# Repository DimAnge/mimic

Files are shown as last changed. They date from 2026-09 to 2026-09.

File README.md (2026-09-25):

<p align="center">
  Mimic
</p>

<p align="center">
  A desk buddy that looks back.<br>
  A Raspberry Pi Pico W, a 128&times;64 OLED and two buttons.
</p>

<p align="center">
  
  
  
  
</p>

<p align="center">
  <a href="https://DimAnge.github.io/mimic/"><b>Try the interface in your browser &rarr;</b></a>
</p>

---

Mimic sits next to the keyboard and keeps an eye on things. It knows the weather,
what is playing, how long until the next meeting, how hard the PC is working, and
how much of the Claude usage window is left — and it pulls a face about all of it.

<p align="center">
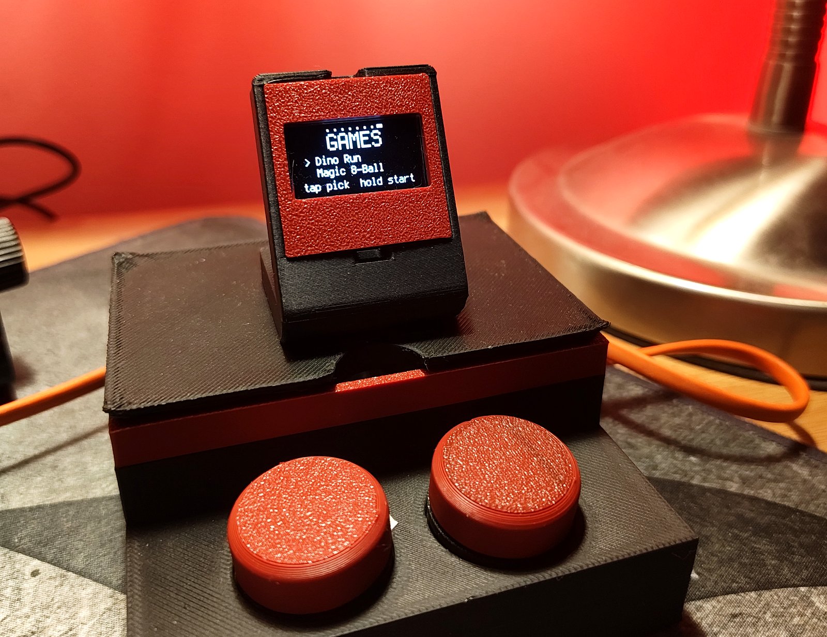
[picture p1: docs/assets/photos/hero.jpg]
Mimic on a desk: a red and black printed case holding an OLED showing the games menu, with two large round buttons in front
  
</p>

<p align="center">
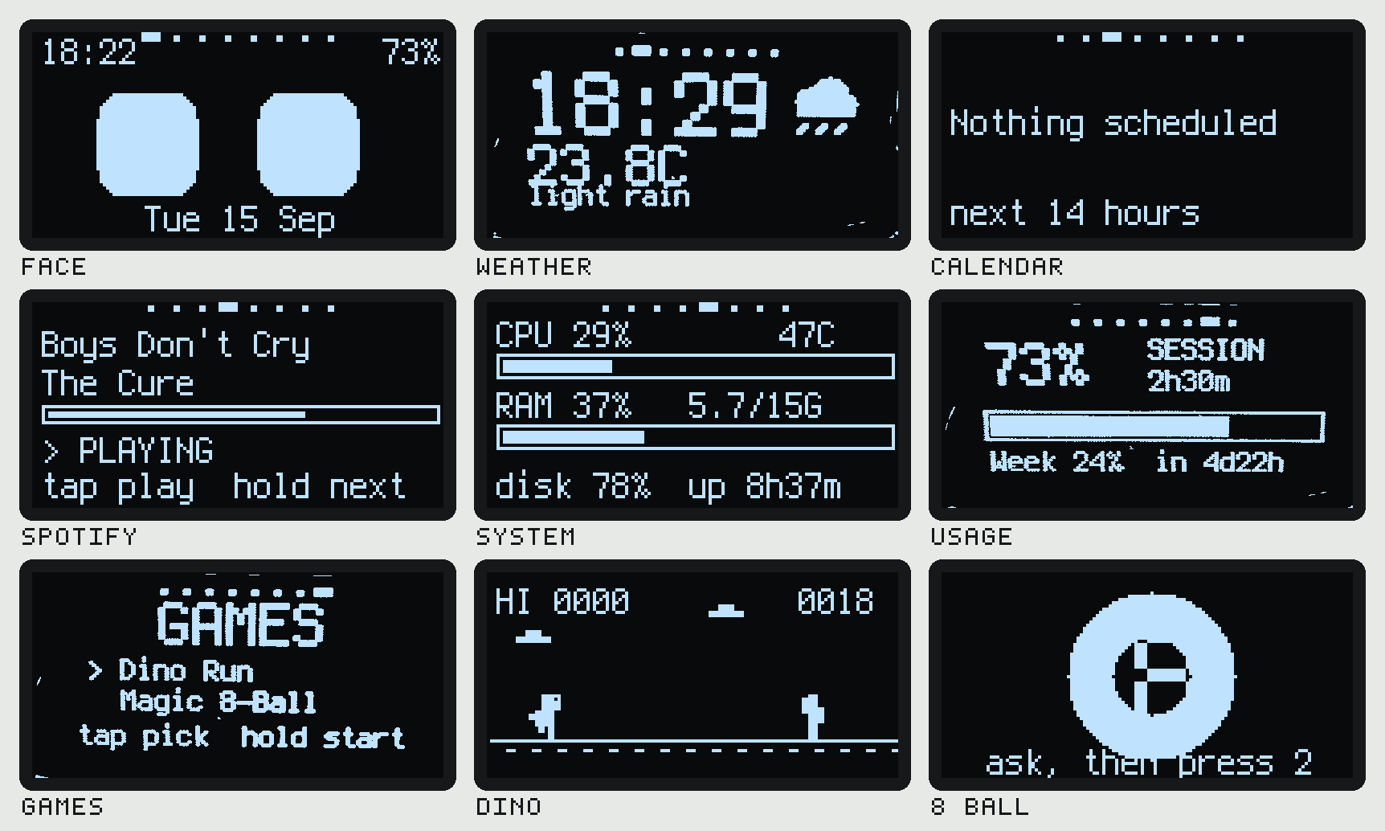
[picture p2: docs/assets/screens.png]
All nine Mimic screens: face, weather, calendar, Spotify, system, usage, games, dino and the magic eight ball
  
</p>

<p align="center">
  <sub>Screens are real frames, not mockups. Most were dumped over USB by
  <code>screenshot.py</code>; the weather, usage and games panels were recovered
  from close-up photographs and thresholded back to two colours.</sub>
</p>

## Why this exists

Mimic started as a private project with two goals: learn electronics properly by
building something that has to work every day, and write Python outside the
analysis scripts I write for work — event loops, hardware constraints, a small
HTTP service, and code that has to survive being unplugged.

It is a learning project, not a product. Some of it is solved the long way round
because the long way round was the point. If you are building your own, the
troubleshooting section below is where most of the learning ended up.

## Contents

- [Why this exists](#why-this-exists)
- [The screens](#the-screens)
- [Controls](#controls)
- [Bill of materials](#bill-of-materials)
- [Wiring](#wiring)
- [Getting it running](#getting-it-running)
- [Configuration](#configuration)
- [How it starts](#how-it-starts)
- [The bridge](#the-bridge)
- [The case](#the-case)
- [Repository layout](#repository-layout)
- [Troubleshooting](#troubleshooting)
- [Roadmap](#roadmap)
- [License](#license)

## The screens

Button 1 walks through the tabs and jumps home when held. Button 2 does whatever
the current tab needs.

| Tab | What it shows | Button 2 |
| --- | --- | --- |
| `FACE` | Animated eyes, a clock, the date, and a note icon while music plays | Cycles the seven moods by hand, for 20 seconds |
| `WEATHER` | A clock big enough to read across the room, temperature and conditions | — |
| `CALENDAR` | The next three events from a private iCal feed | Pages through them |
| `SPOTIFY` | Track, artist and progress, via the Spotify Web API | Tap plays or pauses, hold skips |
| `SYSTEM` | CPU, memory, disk, temperature and uptime of the PC beside it — and the Pico's own IP when the bridge is unreachable | — |
| `TIMER` | Countdown with eight presets from 5 to 60 minutes | Tap starts or stops, hold cycles the preset |
| `USAGE` | Session and weekly Claude usage, with both reset countdowns | — |
| `GAMES` | A menu holding the dino runner and a magic eight ball | Tap moves the cursor, hold starts the game |

Everything the bridge knows arrives in a single `GET /status`, so one request
feeds the calendar, system, usage and Spotify tabs at once.

The two games live in `dino.py` and `eightball.py` and are imported on first
launch rather than at boot — they are the largest modules in the project, and
CircuitPython compiles every `.py` as it imports it, so deferring them cuts
seconds off startup. Inside a game, button 1 backs out to the menu instead of
changing tab.

## Controls

Two buttons, two gestures. A hold is 0.6 s.

| Where | Button 1 | Button 2 tap | Button 2 hold |
| --- | --- | --- | --- |
| Any tab | Next tab | See the table above | See the table above |
| Any tab, held | Home (FACE) | — | — |
| Games menu | Next tab | Move the cursor | Start the selected game |
| In a game | Back to the menu | Jump / shake | — |
| Meeting popup | — | Dismiss | — |

After 45 seconds without a press it returns to FACE on its own — except on
SPOTIFY while something is playing, which stays put.

### What the face is reacting to

Left alone, the mood is not random. Context decides it, in this order, and the
first match wins:

| Priority | Condition | Mood |
| --- | --- | --- |
| 1 | The timer is running | angry — focused, do not disturb |
| 2 | Claude session usage ≥ 90% | surprised |
| 3 | Night | sleepy |
| 4 | The PC has been up more than 2 days | sleepy — it could use a reboot |
| 5 | Music is playing | happy |
| 6 | The weather is notable | sad or happy |
| 7 | Nothing in particular | neutral |

Pressing button 2 on the FACE tab overrides this for 20 seconds, then context
takes over again.

### Screenshots

The SSD1306 cannot be read back — `fill_row` needs a 16-bit colourspace — so
`screenshot.py` walks `display.root_group` and redraws it into a 1-bit buffer,
then prints it over USB. Press `s` in the serial console to capture whatever is
on screen, and `tools/shot.py` turns the dump into a PNG:

```bash
python3 tools/shot.py --paste /tmp/dumps.txt --bezel \
  --names face,calendar,spotify,system,dino,eightball
```

Most screen images in this README came out of that. Three of them would not sit
still long enough to capture — weather, usage and the games menu — so they were
photographed close up instead and put back through `tools/make_photos.py`, which
finds the glass in the photo, squares it to 128 x 64 and thresholds it back to
two colours. Close enough that you cannot tell which is which above.

A meeting popup interrupts any tab when the next calendar event is close.

Burn-in protection runs underneath all of it: the whole frame shifts by a pixel
every few minutes and brightness drops at night. There is no idle sleep — an
idle timeout was tried and removed, because a desk buddy that blanks itself
while you are sitting right there is just a dark rectangle.

## Bill of materials

| Part | Notes |
| --- | --- |
| Raspberry Pi Pico W | Wi-Fi is 2.4 GHz only |
| SSD1306 OLED, 0.96", I2C | 128&times;64, monochrome — there is no colour anywhere in this project |
| 2 &times; tactile buttons | 6&times;6 mm switches on ~25.4 mm pre-assembled discs |
| Passive buzzer module | Plays arbitrary frequencies, so short melodies work |
| Half-size breadboard | Trim the top rail strip so it drops into the tray |
| Female-to-male Dupont jumpers | Nine connections, no soldering |
| USB cable and a 3D printer | For power, code and the case |

## Wiring

<p align="center">
  Mimic wiring map
</p>

| Signal | Pico W pin | Breadboard hole | Goes to |
| --- | --- | --- | --- |
| I2C data | `GP0` — pin 1 | 1a | OLED `SDA` |
| I2C clock | `GP1` — pin 2 | 2a | OLED `SCL` |
| Ground | `GND` — pin 38 | 3j | OLED `GND` |
| 3V3 out | `3V3` — pin 36 | 5j | OLED `VCC` |
| Button 1 | `GP2` — pin 4 | 4a | Button 1 leg A |
| Ground | `GND` — pin 3 | 3a | Button 1 leg B |
| Button 2 | `GP3` — pin 5 | 5a | Button 2 leg A |
| Ground | `GND` — pin 8 | 8a | Button 2 leg B |
| Buzzer signal | `GP15` — pin 20 | 20a | Buzzer `SIG` |
| 5V | `VBUS` — pin 40 | 1j | Buzzer `VCC` |
| Ground | `GND` — pin 18 | 18a | Buzzer `GND` |

The Pico straddles the channel of a half-size breadboard, so row *n* on the `a`
side is physical pin *n*, and row *n* on the `j` side is pin *41 − n*. The buzzer
runs from `VBUS` rather than `3V3`; everything else is on the 3V3 rail.

Breadboard positions for this exact build are in
[`hardware/README.md`](hardware/README.md).

Check every connection against the table before powering anything up, and check
again after any work on the case. Most faults on this build were a connector
that had worked loose, not code.

## Getting it running

**1. Flash CircuitPython.** Hold `BOOTSEL` while plugging the Pico W in, then
drop the `.uf2` onto the `RPI-RP2` drive. It reboots as `CIRCUITPY`.

**2. Add the libraries.** From the matching CircuitPython bundle, copy into
`/lib` on `CIRCUITPY`:

```
adafruit_display_text/
adafruit_displayio_ssd1306.mpy
adafruit_connection_manager.mpy
adafruit_requests.mpy
```

**3. Add your settings.** Copy `settings.toml.example` to `settings.toml` on the
board and fill it in. `settings.toml` is gitignored; keep it that way.

```toml
WIFI_SSID         = "your-network"
WIFI_PASSWORD     = "your-password"
BRIDGE_URL        = "http://192.168.1.42:8080/status"
OPENWEATHER_TOKEN = "your-openweather-key"
```

Find the bridge address with `hostname -I | awk '{print $1}'` on the PC.

**4. Deploy.** All seven files, to the root of the drive, not `/lib`:

```bash
cp code.py app.py eyes.py dino.py eightball.py sfx.py icons.py \
   /media/$USER/CIRCUITPY/ && sync
tio /dev/ttyACM0    # watch it boot
```

`code.py` and `app.py` are a pair and must be deployed together: `code.py` is a
launcher of about fifty lines, and the entire program lives in `app.py`. Copying
one without the other leaves the board running a mismatched half.

Then eject the drive properly before unplugging. `sync` alone is not enough —
see Troubleshooting.

**5. Start the bridge** on the PC Mimic lives next to — see below.

## Configuration

Everything the board needs is in `settings.toml` on the CIRCUITPY drive. There
is no config file in the repository.

| Key | What it does |
| --- | --- |
| `WIFI_SSID` | 2.4 GHz network name — the Pico W radio does not do 5 GHz |
| `WIFI_PASSWORD` | Network password |
| `BRIDGE_URL` | Full URL of the bridge's status endpoint, e.g. `http://192.168.1.42:8080/status`. The Spotify control routes are derived from it |
| `OPENWEATHER_TOKEN` | OpenWeather API key for the weather tab |

The city is set in `app.py` (`CITY = "Athens,GR"`), along with the thresholds
worth knowing about: `MEETING_WARN_MIN` for how far ahead the popup appears,
`UPTIME_TIRED_MIN` and `USAGE_ALERT_PCT` for the mood triggers, and the various
`*_REFRESH` intervals.

## How it starts

`code.py` is a launcher of about fifty lines. It imports `app.py`, which never
returns unless something goes wrong, and handles the two ways it can go wrong on
a desk with no computer attached.

**The network stack can wedge.** On a cold power-on the Pico can join Wi-Fi and
get an address, yet pass no traffic at all: every connection times out with
`EINPROGRESS` and even DNS fails. Once in that state it never recovers on its
own, and rebuilding the socket pool does not help. A soft reset clears it — but
only once the network is genuinely ready, which can take a minute or two after
power-on.

So `app.py` watches for it. Two bridge failures in a row could just mean the PC
is off, so it then tries a DNS lookup: if that fails too while Wi-Fi claims to
be up, the stack is dead rather than the bridge. It raises `NetworkStuck`, and
`code.py` answers with `supervisor.reload()`.

That can only happen ten times. The count lives in `microcontroller.nvm[0]`,
because ordinary variables do not survive a reset. It goes back to zero on a
genuine power-on and on the first successful bridge fetch, so a network that is
merely slow gets as many tries as it needs across boots, while one that is truly
broken cannot reset the board forever. A fresh board's NVM reads 255, which is
treated as zero.

**A crash should not be fatal.** When a CircuitPython program raises, the board
prints the traceback and waits for a keypress on the serial console — which on a
desk looks identical to a dead device. Any other exception is caught, printed,
and followed by a five-second pause and a restart. `Ctrl-C` still drops you into
the REPL, because `KeyboardInterrupt` is not an `Exception` subclass and passes
straight through.

`app.py` also pauses a second on cold boot before touching the OLED: on a
power-on everything wakes at the same instant and CircuitPython gets there
before the display is ready to answer on I2C.

## The bridge

The Pico has no business holding Spotify tokens or a private calendar URL, so it
doesn't. `bridge/bridge.py` is an HTTP server that runs on the PC, listens on
port 8080, and hands back plain integers and pre-formatted strings — the Pico
never parses an ISO timestamp, because CircuitPython has no `datetime`.

| Endpoint | Returns |
| --- | --- |
| `GET /status` | Everything: Claude usage, CPU, memory, disk, temperature, uptime, the next three calendar events, Spotify state, and the wall clock |
| `GET /spotify/playpause` | Toggles playback |
| `GET /spotify/next` | Skips forward |
| `GET /spotify/previous` | Skips back |

The control routes are GETs so the Pico can fire them in one line. Playback
control needs Spotify Premium; reading what is playing works on any account.

`/status` also carries `clock`, which is how the board sets its RTC. A TLS
handshake on a microcontroller costs seconds at boot, and the bridge is already
being talked to over plain HTTP, so it hands over the wall clock and the Pico
skips the HTTPS time sync entirely. HTTPS remains the fallback when the bridge
is unreachable.

Results are cached per source — 60 s for `ccusage`, 4 s for `/proc`, 5 min for
the calendar, 3 s for Spotify — so polling costs almost nothing.

### Setting it up

The calendar needs two packages; everything else is standard library:

```bash
python3 -m venv ~/desky-venv
~/desky-venv/bin/pip install -r bridge/requirements.txt
```

Credentials live in your home directory, never in the repository:

```bash
echo 'https://your-private-ical-url' > ~/.desky-ical-url
echo 'your-spotify-client-id'        > ~/.desky-spotify-client
chmod 600 ~/.desky-ical-url ~/.desky-spotify-client
```

The iCal URL is a bearer credential — anyone holding it can read your calendar.
Then authorise Spotify once, which writes a refresh token to
`~/.desky-spotify.json`:

```bash
~/desky-venv/bin/python bridge/spotify.py
```

It uses the Authorization Code flow with PKCE, so there is no client secret to
store. The redirect URI must be registered in the Spotify dashboard exactly as
`http://127.0.0.1:8888/callback` — Spotify rejects plain HTTP except loopback
literals, and `localhost` does not count as one.

Install the service so it comes back after a reboot:

```bash
mkdir -p ~/.config/systemd/user
cp bridge/mimic-bridge.service ~/.config/systemd/user/
systemctl --user enable --now mimic-bridge
systemctl --user status mimic-bridge --no-pager
```

The unit sets `PYTHONUNBUFFERED=1` so `journalctl --user -u mimic-bridge -f`
shows output as it happens rather than in blocks.

Editing any bridge file leaves the old process running. Restart after every
change:

```bash
systemctl --user restart mimic-bridge
```

`bridge/cal_debug.py` exists only for troubleshooting the calendar feed — it
prints which calendar the URL belongs to and every occurrence it can see.

If the PC sleeps, Mimic falls back to its offline screens rather than hanging.

## The case

Five printed parts: three of mine, two from MakerWorld.

| Part | Source | What it does |
| --- | --- | --- |
| `tray.stl` | Custom, `hardware/case.scad` | Body: breadboard pocket, USB opening on the right wall, button shelf |
| `lid.stl` | Custom, `hardware/case.scad` | Lifts off on a locating lip, with a cable pass-through |
| `spacer.stl` | Custom, `hardware/case.scad` | Sets the stack height inside the tray so the openings line up |
| Screen stand | [Minimalist OLED 0.96" modular case](https://makerworld.com/en/models/2085334-minimalist-oled-0-96-modern-modular-cases#profileId-2253779) by Maker Engineer | Holds the OLED at a readable angle |
| Button assemblies | [Push button assembly](https://makerworld.com/en/models/1791039-push-button-assembly?from=search#profileId-1908757) by Leroyd | The two ~25.4 mm button discs |

Check each MakerWorld licence before reusing those two — most are Creative
Commons and ask for attribution, some forbid commercial use.

### Printing it

1. **Print the two downloaded parts first** with the settings on their model
   pages. They are quick, and they tell you whether your printer holds tolerance
   before you commit hours to the tray.
2. **Print the tray.** 0.2 mm layers, 15% infill, PLA, no supports, open side up.
   Check the breadboard pocket against your actual breadboard while a reprint is
   still cheap.
3. **Print the spacer and the lid.** Same settings.
4. **Clean the openings.** Clear elephant's foot from the counterbores and the
   USB slot with a craft knife until parts seat without force.
5. **Dry fit everything** before wiring: breadboard into the tray, spacer under
   the stack, buttons into the shelf, screen into its stand, cable through the
   slot.
6. **Assemble and re-test.** Seat the Dupont connectors dry and power it up
   before the lid goes on.

Exporting the custom parts:

```bash
openscad -D 'part="tray"'   -o hardware/stl/tray.stl   hardware/case.scad
openscad -D 'part="lid"'    -o hardware/stl/lid.stl    hardware/case.scad
openscad -D 'part="spacer"' -o hardware/stl/spacer.stl hardware/case.scad
```

**Do not glue the Dupont connectors.** Superglue wicks between the metal
contacts and insulates them: the joint looks perfect and conducts nothing. Two
attempts at custom button caps also failed here, both because the boss length
was measured from the wrong reference face — which is why the discs above are a
download rather than a design.

## Repository layout

```
mimic/
├── code.py                 # launcher: stuck-network and crash recovery
├── app.py                  # the program: all eight tabs and the main loop
├── eyes.py                 # the face: moods, blinking, gaze, boot animation
├── dino.py                 # the runner, imported on first launch
├── eightball.py            # the magic eight ball, imported on first launch
├── sfx.py                  # the buzzer and its melody table
├── icons.py                # weather sprites
├── screenshot.py           # framebuffer dumper, see tools/shot.py
├── settings.toml.example   # Wi-Fi, bridge URL and weather key template
├── bridge/
│   ├── bridge.py           # PC-side HTTP service
│   ├── spotify.py          # one-time PKCE login, and the bridge's module
│   ├── cal_debug.py        # calendar feed troubleshooting
│   ├── requirements.txt
│   └── mimic-bridge.service
├── hardware/
│   ├── case.scad           # tray, lid and spacer
│   ├── stl/
│   └── README.md
├── docs/                   # the GitHub Pages site
│   ├── index.html          # one file, includes the browser simulator
│   └── assets/             # logo, favicons, wiring map, social preview
└── tools/                  # shot.py and the asset generators
```

## Troubleshooting

**The board boots to an error after a deploy.** The write did not flush. Copy
again with `&& sync`, eject the drive, and watch the console with
`tio /dev/ttyACM0`.

**A bare `OSError: [Errno 5]` with no traceback.** The filesystem on the board is
corrupted, almost always from unplugging while a write was still in flight.
`sync` flushes your PC's cache, but the Pico can still be mid-write: eject the
drive from the file manager, or `udisksctl unmount -b /dev/sdX1`, before pulling
the cable. To recover, first copy `settings.toml` and `lib/` off the board if
you still can, then in the REPL:

```python
import storage
storage.erase_filesystem()
```

The board reboots with an empty CIRCUITPY drive. Put `lib/`, `settings.toml`
and the seven program files back.

**It will not join the network.** The Pico W radio is 2.4 GHz only. A combined
2.4/5 GHz SSID sometimes works and sometimes does not; give the 2.4 GHz band its
own name if you can.

**No serial device on Linux.** Add yourself to `dialout` and log back in, then
stop ModemManager grabbing the port:

```bash
sudo usermod -aG dialout $USER
sudo systemctl mask ModemManager
```

**A button stopped responding after assembly.** Check for glue before checking
the code. Superglue wicks between Dupont contacts and insulates them perfectly.
Wiggle the connector to crack the joint, re-seat it dry, and let the pinched
barrel do the gripping.

**Python tooling refuses to install.** Check whether conda is shadowing the
system Python with an older version, and point `pipx` at the real one, for
example `/usr/bin/python3.12`.

**`EINPROGRESS` on every request.** Nine times out of ten this is the wrong IP
in `BRIDGE_URL`: the Pico is connecting to an address where nothing answers.
Compare it with `hostname -I` on the PC. PCs on DHCP change address after a
router restart, so give the PC a **DHCP reservation** in the router and the
address stops moving. The remaining case is the cold-boot wedge above, which
`code.py` handles on its own — the screen shows `Network reset n/10` while it
does.

**Everything reads zero, or one section never populates.** Same first check:
`BRIDGE_URL` against `hostname -I`. A wrong address fails quietly. When the
bridge is unreachable the SYSTEM tab shows the Pico's own IP and the last error,
which is usually enough to tell which side is wrong.

**The screen shows stale numbers.** The bridge is not running, or the PC is
asleep. `systemctl --user status mimic-bridge --no-pager`, and
`journalctl --user -u mimic-bridge -f` to watch it live.

**Usage shows `--%`.** The usage tab reads `ccusage json`, and that output format
is undocumented and not a stable API — a Claude Code update can change or
remove it without warning. Run `ccusage json` by hand; if it errors or the keys
have moved, `read_usage()` in `bridge.py` is the place to adapt. If `ccusage` is
not on the service's `PATH`, set `CCUSAGE_BIN` to its full path in the unit.

**The calendar says nothing is scheduled when something is.** The bridge looks
seven days ahead and the tab shows the next three, so an empty tab means the
feed really has nothing timed in that window. Run
`python3 bridge/cal_debug.py`, which prints which calendar the feed belongs to
and every occurrence it can see. All-day entries are ignored on purpose —
birthdays and public holidays are not meetings and should not raise a popup.

## Roadmap

- [x] Face reacts to context — timer, usage, night, uptime, music, weather
- [ ] Persist the dino high score across restarts
- [ ] Top-mounted screen holder integrated into the tray, replacing the separate stand
- [ ] A task button that cycles today's tasks and marks them done

Dropped on purpose: Gmail notifications (too much moving parts for the payoff)
and anything that depends on colour.

## License

MIT — see [LICENSE](LICENSE).

Built with [CircuitPython](https://circuitpython.org/), Adafruit's display
libraries, and [OpenSCAD](https://openscad.org/). The screen stand and button
discs are other people's models — see [The case](#the-case) for links and
licences.

The logo, the wiring diagram, the social image and the project site were made
with help from Claude (Anthropic). The hardware and the mistakes are
mine.

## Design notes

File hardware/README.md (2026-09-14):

# Hardware

## Breadboard layout

The reference build sits on a half-size breadboard with the top rail strip
trimmed off so it drops into the case tray.

| Component | Connection | Breadboard hole |
| --- | --- | --- |
| OLED | `SDA` -> `GP0`, pin 1 | 1a |
| OLED | `SCL` -> `GP1`, pin 2 | 2a |
| OLED | `GND`, pin 38 | 3j |
| OLED | `VCC` -> `3V3`, pin 36 | 5j |
| Button 1 | leg A -> `GP2`, pin 4 | 4a |
| Button 1 | leg B -> `GND`, pin 3 | 3a |
| Button 2 | leg A -> `GP3`, pin 5 | 5a |
| Button 2 | leg B -> `GND`, pin 8 | 8a |
| Buzzer | `SIG` -> `GP15`, pin 20 | 20a |
| Buzzer | `VCC` -> `VBUS`, 5V, pin 40 | 1j |
| Buzzer | `GND`, pin 18 | 18a |

Row *n* on the `a` side of the channel is physical pin *n*; row *n* on the `j`
side is pin *41 − n*. That is the whole trick to reading this table against the
board.

Wire colours used in the diagrams: red for 3V3, dark grey for ground, blue for
I2C data, yellow for I2C clock, green for button inputs, purple for the buzzer
signal.

## Checking the wiring

Check every connection against the table above:

- after wiring, before loading `code.py`
- after any work on the case
- after anything involving glue

## Printed parts

| Part | Source |
| --- | --- |
| `tray.stl` | Custom, `case.scad` |
| `lid.stl` | Custom, `case.scad` |
| `spacer.stl` | Custom, `case.scad` |
| Screen stand | [Minimalist OLED 0.96" modular case](https://makerworld.com/en/models/2085334-minimalist-oled-0-96-modern-modular-cases#profileId-2253779) by Maker Engineer |
| Button assemblies | [Push button assembly](https://makerworld.com/en/models/1791039-push-button-assembly?from=search#profileId-1908757) by Leroyd |

Check the licence on each MakerWorld model before reusing it, and say so here if
you remixed rather than printed as-is.

`case.scad` builds the three custom parts. Set the `part` variable and export:

```bash
openscad -D 'part="tray"'   -o stl/tray.stl   case.scad
openscad -D 'part="lid"'    -o stl/lid.stl    case.scad
openscad -D 'part="spacer"' -o stl/spacer.stl case.scad
```

Print settings: 0.2 mm layers, 15% infill, PLA, no supports. The tray prints
open-side up. Print the two MakerWorld parts first — they are quick, and they
tell you whether your printer is holding tolerance before you commit hours to
the tray.

### Known dimensions (v6)

| Feature | Value |
| --- | --- |
| Breadboard pocket | 85 x 57 mm |
| Button counterbore | 25.39 mm |
| Button disc slot | 22 x 16 mm (clears Dupont connectors) |
| USB opening | right wall |
| Lid | locating lip plus cable pass-through slot |
| Spacer | sets the stack height inside the tray |

### Assembly warning

Do not glue Dupont connectors. Superglue wicks between the metal contacts and
insulates them; the joint looks perfect and conducts nothing. The pinched barrel
grip is enough on its own. If a button has gone dead after assembly, wiggle the
connector to crack any glue and re-seat it dry.

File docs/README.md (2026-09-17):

# The Mimic site

`index.html` is the whole site: one file, no build step, no dependencies beyond
two web fonts. Open it in a browser to work on it.

## Publishing

Either way works. Pick one.

**Branch setting (simplest).** Settings → Pages → Source: *Deploy from a branch*
→ branch `main`, folder `/docs`. Push, wait a minute, done.

**Actions workflow.** Settings → Pages → Source: *GitHub Actions*. The workflow
in `.github/workflows/pages.yml` then publishes `docs/` on every push to `main`.

`.nojekyll` is there so GitHub serves the folder as-is.

## Before the first push

Replace `DimAnge` in these places:

- `docs/index.html` — the `og:url` and `og:image` tags, three GitHub links
- `README.md` — the site link and the footer link

Then set the social image: Settings → General → Social preview → upload
`docs/assets/social-preview.png`.

## Assets

| File | Use |
| --- | --- |
| `logo.svg` | Horizontal lockup, site header and README |
| `logo-mark.svg`, `logo-mark-512.png` | Square mark, avatars |
| `favicon.svg`, `favicon-32.png`, `favicon-180.png` | Browser and iOS icons |
| `wordmark.svg` | Type only |
| `social-preview.png` | 1280×640 card for GitHub, link previews |
| `wiring.svg`, `wiring.png` | The wiring map |
| `screens.png` | Contact sheet, built by `tools/make_sheet.py` from real captures |
| `shots/` | Real screen captures from the device |
| `photos/` | Device photographs, resized by `tools/make_photos.py` |
| `classic/` | The first identity: rounded case, glowing pixel eyes, blue-white screen |
| `alt/` | The two directions not chosen — stamp and sketch, see `alt/compare.png` |

The current identity is the bracket mark: a face held in square brackets, one
ink, no bezel and no glow. It is generated by `tools/make_bracket_assets.py`.

Everything is generated geometry — no fonts are needed to render the logos, so
they survive being embedded anywhere.

To go back to the first identity, copy `classic/` over the top:

```bash
cp docs/assets/classic/* docs/assets/
```

Regenerate after editing the scripts in `tools/`:

```bash
pip install cairosvg
python3 tools/make_assets.py
python3 tools/make_wiring.py
python3 tools/make_bracket_assets.py   # the current logo set
python3 tools/make_alt_logos.py        # the directions not chosen
```

## Real screenshots

`screenshot.py` on the board prints the framebuffer over USB serial; `tools/shot.py`
turns that into a PNG in this palette.

```bash
python3 tools/shot.py /dev/ttyACM0 --bezel        # live, press "s" in the console
python3 tools/shot.py --paste dump.txt --bezel    # from a saved console dump
```

Dumps land in `docs/assets/shots/`. Rebuild the contact sheet from them with:

```bash
python3 tools/make_sheet.py FACE=docs/assets/shots/face.png \
  CALENDAR=docs/assets/shots/calendar.png SPOTIFY=docs/assets/shots/spotify.png \
  SYSTEM=docs/assets/shots/system.png DINO=docs/assets/shots/dino.png \
  "8 BALL=docs/assets/shots/eightball.png"
```

## Colours

| Token | Hex | Where |
| --- | --- | --- |
| Paper | `#E7E9E6` | Page background |
| Ink | `#16181A` | Text, the case |
| Ink 2 | `#5B6166` | Secondary text |
| Rule | `#C9CDC8` | Hairlines |
| Screen | `#080A0C` | Inside the bezel |
| Glow | `#BFE3FF` | Lit pixels |

Colour is only used where it carries information: the wire map uses red for 3V3,
dark grey for ground, blue for I2C data, yellow for I2C clock, green for button
inputs and purple for the buzzer signal. Everything else is 1-bit, like the
device.

## The simulator

The device in the hero is a real 128×64 framebuffer. Each screen draws white
shapes and text onto an off-screen canvas, then every pixel is thresholded to on
or off before being scaled up — which is why the type looks like the real display
rather than smooth browser text.

To add a screen, add an entry to the `SCREENS` array with a `draw` function and
handle it in `b2Tap`. The tab dots and the list further down the page build
themselves from that array.

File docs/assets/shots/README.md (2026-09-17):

# Screen captures

Real frames, not mockups.

**Captured over USB.** `screenshot.py` on the Pico walks `display.root_group`,
redraws it into a 1-bit buffer and prints it as hex; `tools/shot.py` on the PC
turns that back into a PNG.

```bash
tio /dev/ttyACM0                 # walk the tabs, press "s" once per screen
cat > /tmp/dumps.txt             # paste the console output, then Ctrl-D
python3 tools/shot.py --paste /tmp/dumps.txt --bezel \
  --names face,calendar,spotify,system,dino,eightball
```

**Recovered from photographs.** `weather.png`, `usage.png` and `games.png` come
from close-up photos instead: `tools/make_photos.py` finds the glass in the
photo, squares it to 128 x 64, thresholds it back to two colours and drops the
dust specks.

```bash
python3 tools/make_photos.py /path/to/photos
```

Then rebuild the contact sheet used in the README:

```bash
python3 tools/make_sheet.py --cols=3 \
  FACE=docs/assets/shots/face.png WEATHER=docs/assets/shots/weather.png \
  CALENDAR=docs/assets/shots/calendar.png SPOTIFY=docs/assets/shots/spotify.png \
  SYSTEM=docs/assets/shots/system.png USAGE=docs/assets/shots/usage.png \
  GAMES=docs/assets/shots/games.png DINO=docs/assets/shots/dino.png \
  "8 BALL=docs/assets/shots/eightball.png"
```

Still missing: the timer screen.

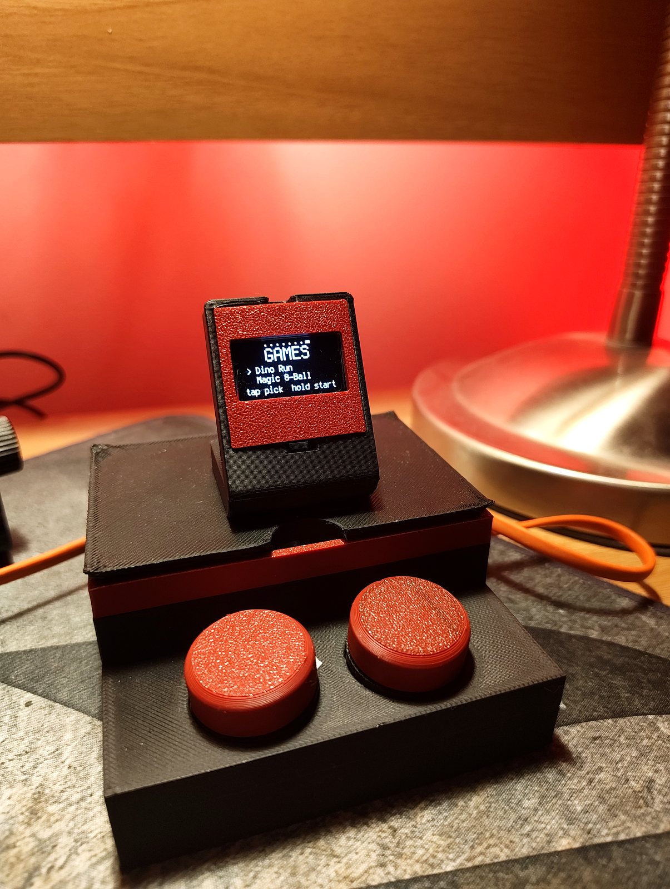
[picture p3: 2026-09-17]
docs/assets/photos/stand.jpg

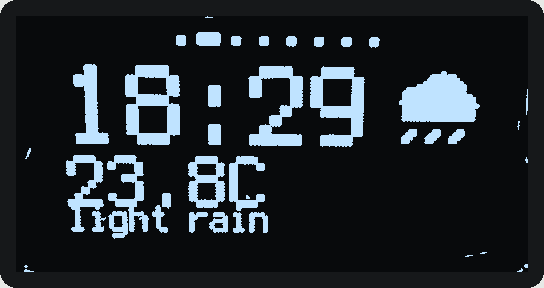
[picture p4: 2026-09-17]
docs/assets/shots/weather.png

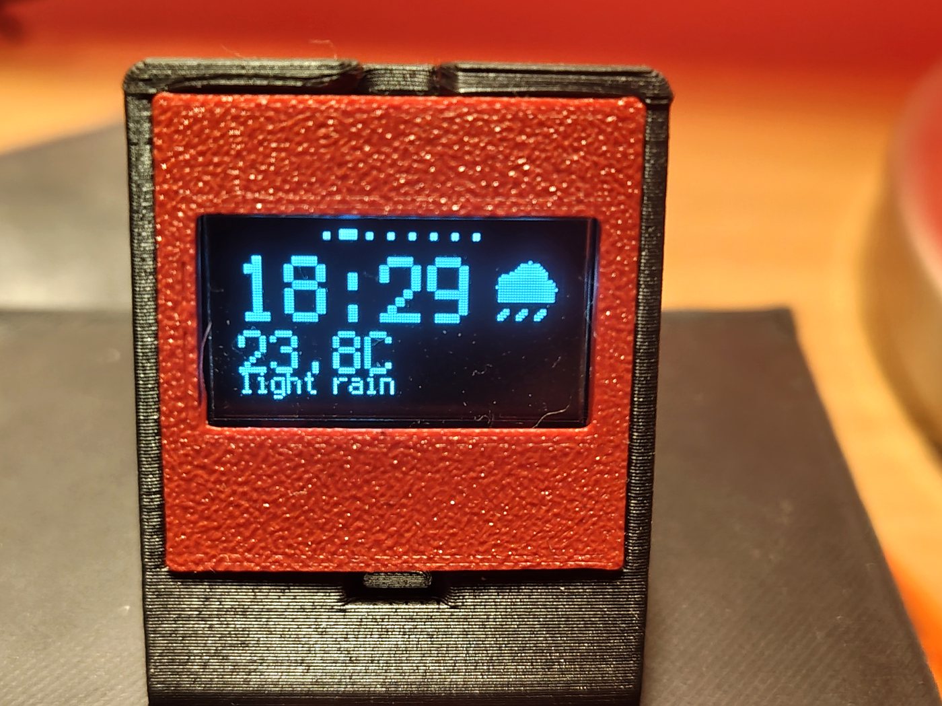
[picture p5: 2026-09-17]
docs/assets/photos/weather.jpg

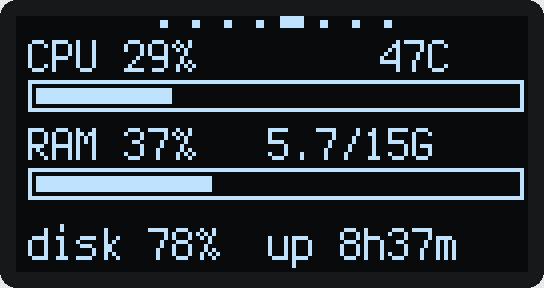
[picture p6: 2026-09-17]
docs/assets/shots/system.png

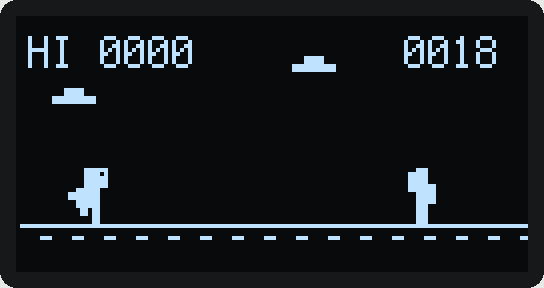
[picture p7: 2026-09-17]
docs/assets/shots/dino.png

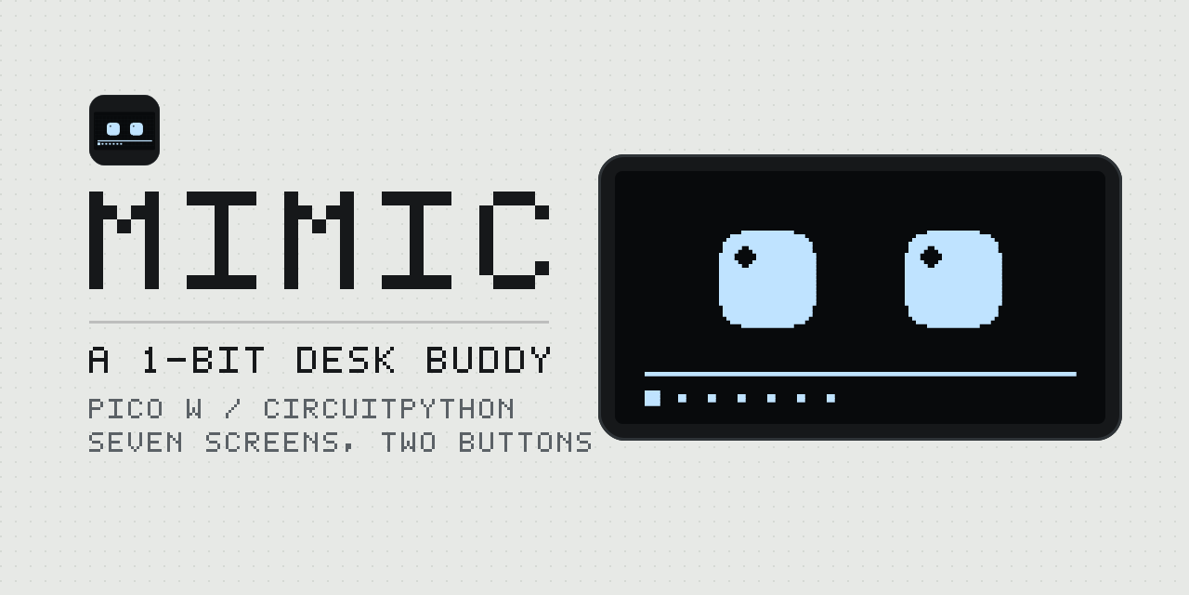
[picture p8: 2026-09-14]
docs/assets/classic/social-preview.png

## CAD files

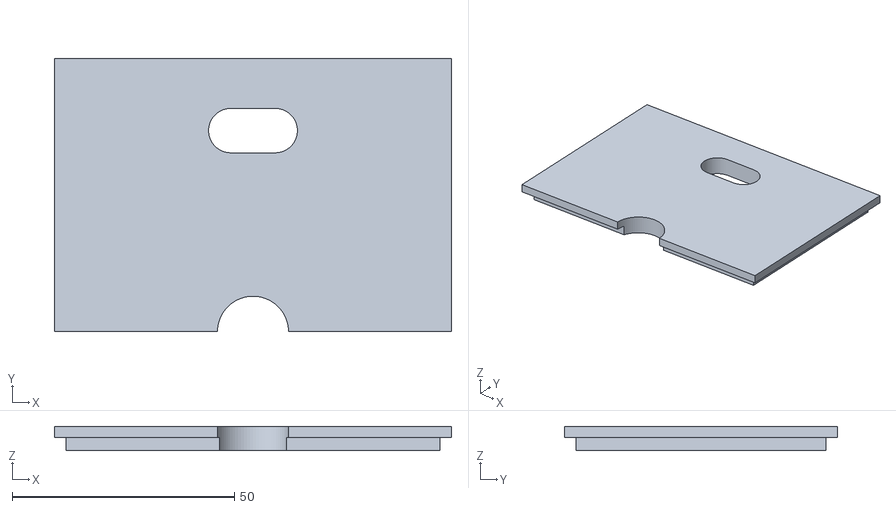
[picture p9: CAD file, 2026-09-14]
hardware/stl/lid.stl
89.4 x 61.4 x 5.50

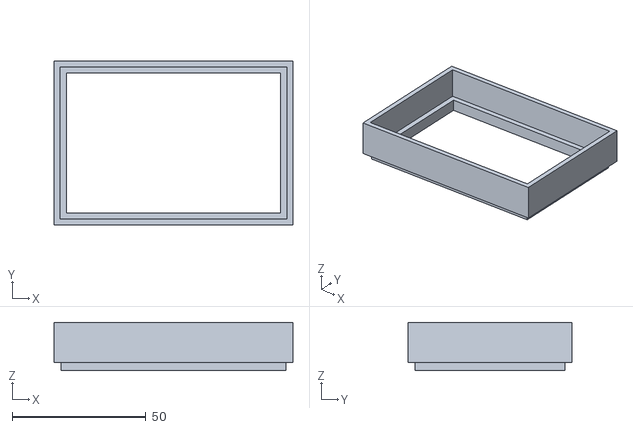
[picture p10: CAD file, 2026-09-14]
hardware/stl/spacer.stl
89.4 x 61.4 x 18.0

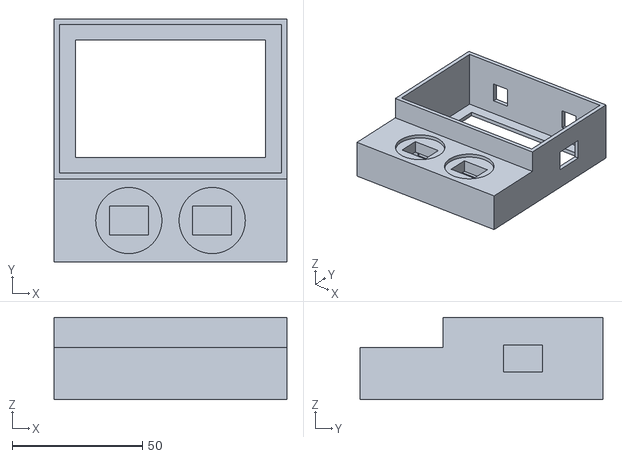
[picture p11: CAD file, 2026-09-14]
hardware/stl/tray.stl
89.4 x 93.4 x 31.5

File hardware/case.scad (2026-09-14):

/* =====================================================================
   DESK HELPER — v6
   Closed box + lid. Screen mounts on top, separately.
   ---------------------------------------------------------------------
   WHAT CHANGED FROM v5
     - screen holder removed entirely; you build that on top of the lid
     - box walls raised so the lid clears the Pico and the jumper wires
     - removable lid with a locating lip
     - cable pass-through in the lid for the screen wires
     - USB cutout added — needed now that the walls are taller than
       the Pico's socket

   STILL BUILT AROUND YOUR STLs
     Button: cap / stem / guide / mount. The 24.89 mm mount disc drops
     into a counterbore in the front shelf and finishes flush. Cap ends
     up 9.4 mm above the shelf.

   HOLDING THE WIRES ON, WITHOUT SOLDER OR HOT GLUE
     Under each button the shelf floor has three slots. The single
     narrow one is a friction clamp: push the jumper wire into it and
     it grips by itself. The pair behind take a zip tie if you have
     one. Either way the wire is anchored ~10 mm downstream of the
     connector, so tugging the cable never levers the connector off
     the switch leg. That is what actually keeps it attached.

     Do NOT superglue near the switch. It wicks along stranded wire
     and into seams, and the stem has to slide freely just above.

   >>> CHECK usb_side BEFORE PRINTING <<<
   Look down at the tray with the buttons nearest you. If the Pico's
   USB socket points right, leave usb_side = 1. If left, set it to -1.
   ===================================================================== */

part = "all";     // "coupon" | "lid" | "tray" | "spacer" | "all"

/* ---------- FROM YOUR BUTTON STLs — already measured ---------------- */
mount_d    = 24.89;  // diameter of the mount disc
mount_t    = 1.80;   // thickness of the disc
mount_boss = [22.0, 16.0]; // slot below the disc. Yours arrive with
                           //   the tactile switch already fitted, and the
                           //   Dupont connectors on the legs splay out
                           //   wider than the switch body itself. This
                           //   cavity is fully hidden under the shelf, so
                           //   it costs nothing to leave it generous.

/* ---------- BREADBOARD ---------------------------------------------- */
bb_len     = 83.0;
bb_wid     = 55.0;
bb_h       = 9.5;    // INCLUDING adhesive backing

/* ---------- HEIGHT --------------------------------------------------- */
headroom   = 20.0;   // clear space above the breadboard surface.
                     //   A male Dupont housing stands ~11 mm proud and
                     //   the wire bends over above that. Lower this to
                     //   16 for a squatter box if your wiring is flat.

/* ---------- USB ------------------------------------------------------ */
usb_side   = 1;      // 1 = right wall, -1 = left wall
usb_w      = 15.0;   // opening width
usb_z0     = 10.5;   // bottom of the opening, above the floor
usb_z1     = 21.0;   // top. The socket itself only reaches ~17.4,
                     //   but a micro-USB plug's moulding is taller than
                     //   the socket, so the opening has to clear that
                     //   rather than just the connector.

/* ---------- LID ------------------------------------------------------ */
lid_t      = 2.5;
lid_lip    = 3.0;    // depth of the locating lip
lid_clr    = 0.4;    // clearance so it lifts off easily
cable_w    = 20.0;   // pass-through for the screen wires
cable_d    = 10.0;
cable_back = 14.0;   // its centre, measured in from the back wall

/* ---------- SPACER COLLAR -------------------------------------------- */
spacer_h   = 15.0;   // how much height it adds. 10-20 all work.
ledge_t    = 2.0;    // ledge the lid's lip lands on
sp_lipw    = 2.0;    // wall of the locating lip underneath

/* ---------- BUZZER --------------------------------------------------- */
buz_bay    = false;  // true = adds an open bay at the back,
                     //   which makes the box 28 mm deeper
buz_w      = 24.0;   // CONFIRM WITH CALIPERS
buz_d      = 20.0;
buz_wall   = 1.6;
buz_lip    = 6.0;
buz_clr    = 0.8;

/* ---------- FITS ----------------------------------------------------- */
mount_clr  = 0.5;    // clearance on the mount disc; it should drop in
fit        = 1.0;    // clearance per side around the breadboard.
                     //   Nominal half-size boards are 83 x 55 but they
                     //   vary, and moulding flash adds a little. At 1.0
                     //   the pocket is 85 x 57, which swallows anything
                     //   in that class. The adhesive backing stops it
                     //   sliding, so a loose pocket costs you nothing.
wall       = 2.2;
floor_t    = 2.0;

/* ---------- BUTTON SHELF --------------------------------------------- */
btn_count  = 2;
btn_gap    = 32.0;   // centre to centre; must exceed mount_d
tie_slot   = [8.0, 2.6];   // zip-tie slots for wire strain relief
tie_dy     = [7, 12];      // their offsets behind the button centre
pinch_slot = [12.0, 1.3];  // friction slot — press a jumper wire into
                           //   this and it grips on its own, no tie and
                           //   no glue needed. 1.3 suits ~1.6 mm jumper
                           //   wire; widen to 1.5 if it will not go in.
pinch_dy   = -9;           // in front of the button centre
shelf_d    = 32.0;
shelf_top  = 20.0;
shelf_t    = 8.0;
$fn        = 72;

/* ---------- DERIVED --------------------------------------------------- */
mount_bore  = mount_d + mount_clr;
shelf_bot   = shelf_top - shelf_t;

pocket_l    = bb_len + 2*fit;
pocket_w    = bb_wid + 2*fit;

Z           = floor_t + bb_h + headroom;   // top of the box walls

y_front     = shelf_d;                     // box starts here
y_pocket    = y_front + wall;
y_backwall  = y_pocket + pocket_w;
y_boxback   = y_backwall + wall;
box_d       = y_boxback - y_front;

X = pocket_l + 2*wall;

bay_w       = buz_d + buz_clr + 2*buz_wall;   // module turned 90 deg
bay_d       = buz_w + buz_clr + 2*buz_wall;
Y = buz_bay ? y_boxback + bay_d : y_boxback;

btn_x = [ for (i = [0:btn_count-1])
          X/2 + (i - (btn_count-1)/2) * btn_gap ];

assert(btn_gap > mount_d + 3, "Caps will collide — raise btn_gap.");
assert(shelf_d > mount_d + 5, "Shelf too shallow for the caps.");
assert(shelf_t > mount_t + 2, "Shelf too thin for the counterbore.");
assert(usb_z1 < Z, "USB opening is taller than the wall.");
assert(cable_back > cable_d/2 + 2, "Cable slot runs into the back wall.");

echo(str("Footprint:    ", X, " x ", Y, " mm"));
echo(str("Board pocket: ", pocket_l, " x ", pocket_w,
         " mm (board assumed ", bb_len, " x ", bb_wid, ")"));
echo(str("Box walls:    ", Z, " mm; with lid ", Z + lid_t, " mm"));
echo(str("Caps reach:   ", shelf_top + 9.4, " mm"));
echo(str("Headroom above breadboard: ", headroom, " mm"));
echo(str("With spacer: ", Z + spacer_h + lid_t, " mm total, ",
         headroom + spacer_h, " mm of wire room"));
echo(str("USB opening on the ", usb_side > 0 ? "RIGHT" : "LEFT", " wall"));

/* ===================================================================== */

// Counterbore for the mount disc, plus a slot for everything below it.
module mount_recess(x, y) {
    translate([x, y, shelf_top - mount_t])
        cylinder(h = mount_t + 0.2, d = mount_bore);
    translate([x - mount_boss[0]/2, y - mount_boss[1]/2, shelf_bot - 1])
        cube([mount_boss[0], mount_boss[1], shelf_t - mount_t + 1.2]);
}

module button_shelf() {
    difference() {
        cube([X, shelf_d, shelf_top]);
        // hollow underneath, open at the back into the box
        translate([wall, wall, floor_t])
            cube([X - 2*wall, shelf_d - wall + 0.1, shelf_bot - floor_t]);
        for (x = btn_x) mount_recess(x, shelf_d/2);
        // strain relief: thread a zip tie down one slot and up the other
        // to clamp each button's wires against the shelf floor
        for (x = btn_x) {
            for (dy = tie_dy)
                translate([x - tie_slot[0]/2,
                           shelf_d/2 + dy - tie_slot[1]/2, -1])
                    cube([tie_slot[0], tie_slot[1], floor_t + 2]);
            // friction slot: push the wire in, it holds itself
            translate([x - pinch_slot[0]/2,
                       shelf_d/2 + pinch_dy - pinch_slot[1]/2, -1])
                cube([pinch_slot[0], pinch_slot[1], floor_t + 2]);
        }
    }
}
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

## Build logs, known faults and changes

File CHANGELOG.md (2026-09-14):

# Changelog

All notable changes to Mimic. Dates are the day the change landed on the board.

## Unreleased

### Added
- Spotify tab: playback state over the Spotify Web API with PKCE OAuth, play/pause
  on tap and skip on hold
- Calendar meeting popup, fed by a private iCal URL parsed on the bridge
- Buzzer soundboard of chiptune jingles
- Tab dots along the bottom of every screen
- Games menu holding the dino runner and a magic eight ball, both imported lazily
- Calendar tab showing the next few events, alongside the existing popup
- A date overlay on the face

### Changed
- Bridge now runs as a systemd user service so it starts at login
- Weather tab carries the large clock; the separate clock tab was removed
- Case at v6: breadboard pocket widened to 85x57 mm, button disc slot widened to
  22x16 mm to clear Dupont connectors, screen holder removed pending a top mount

### Removed
- `IDLE_SLEEP`: blanking the screen while someone is sitting at the desk made it
  a dark rectangle rather than a desk buddy
- Gene lookup tab
- Gmail notifications

## 0.1.0

### Added
- First working build: animated face, weather, system stats, timer and usage
- Non-blocking audio via a tone queue
- Edge-detected button handling with timestamp lockouts, no sleep-based debounce
- Burn-in protection: pixel shift plus night and idle dimming

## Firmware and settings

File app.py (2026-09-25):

import board, busio, displayio, terminalio, os, time, wifi, rtc, digitalio, random
import supervisor
import microcontroller
from adafruit_display_text import label
import adafruit_displayio_ssd1306
import i2cdisplaybus
import adafruit_connection_manager
import adafruit_requests

# A cold power-up and a soft reload are very different starts. On a reload
# (saving a file, Ctrl-D in tio) the OLED is already powered and the WiFi
# radio is already warm. On a cold boot everything wakes at the same instant,
# and CircuitPython starts running this file within milliseconds -- before
# the OLED is ready to answer on I2C. Give the hardware a beat first.
COLD_BOOT = supervisor.runtime.run_reason == supervisor.RunReason.STARTUP
if COLD_BOOT:
    time.sleep(1.0)

from eyes import Eyes, _fill as fill_rect
from sfx import Sfx
from icons import draw_weather, SIZE as ICON_SIZE

# dino.py and eightball.py are imported on first use instead of here.
# CircuitPython compiles every .py at import time, and those two are the
# largest modules in the project -- deferring them cuts seconds off boot.
BOOT_T0 = time.monotonic()


def boot_mark(label_text):
    print(f"[boot {time.monotonic() - BOOT_T0:5.2f}s] {label_text}")

# --- 1. CONFIG ---
CITY = "Athens,GR"
UNITS = "metric"

# Put BRIDGE_URL in settings.toml so swapping PCs doesn't mean editing code:
#     BRIDGE_URL = "http://192.168.1.42:8080/status"
# Find the IP with:  hostname -I | awk '{print $1}'
BRIDGE_URL = os.getenv("BRIDGE_URL") or "http://192.168.1.100:8080/status"
BRIDGE_BASE = BRIDGE_URL.rsplit("/", 1)[0]      # drop "/status"

MODES = ["FACE", "WEATHER", "CALENDAR", "SPOTIFY", "SYSTEM", "TIMER",
         "USAGE", "GAMES"]

GAMES = ("Dino Run", "Magic 8-Ball")

MEETING_WARN_MIN = 15        # popup appears this many minutes ahead
UPTIME_TIRED_MIN = 2 * 24 * 60   # PC up this long and the eyes go droopy
USAGE_ALERT_PCT = 90         # usage this high and the eyes look alarmed

WEEKDAYS = ("Sun", "Mon", "Tue", "Wed", "Thu", "Fri", "Sat")
MONTHS = ("Jan", "Feb", "Mar", "Apr", "May", "Jun",
          "Jul", "Aug", "Sep", "Oct", "Nov", "Dec")


def weekday_name(year, month, day):
    """Sakamoto's algorithm -- the RTC doesn't fill in tm_wday for us."""
    table = (0, 3, 2, 5, 0, 3, 5, 1, 4, 6, 2, 4)
    y = year - 1 if month < 3 else year
    idx = (y + y // 4 - y // 100 + y // 400 + table[month - 1] + day) % 7
    return WEEKDAYS[idx]


# --- 2. HARDWARE SETUP ---
btn_mode = digitalio.DigitalInOut(board.GP2)
btn_mode.direction = digitalio.Direction.INPUT
btn_mode.pull = digitalio.Pull.UP

btn_action = digitalio.DigitalInOut(board.GP3)
btn_action.direction = digitalio.Direction.INPUT
btn_action.pull = digitalio.Pull.UP

sfx = Sfx(board.GP15)

def init_display(attempts=6):
    """Bring up the OLED, retrying while it finishes powering on.

    The classic cold-boot failure is busio.I2C raising 'No pull up found on
    SDA or SCL': the display's pull-ups aren't live yet, so the bus looks
    unconnected. Half a second later it's fine.
    """
    for i in range(attempts):
        displayio.release_displays()
        bus = None
        try:
            bus = busio.I2C(board.GP1, board.GP0, frequency=400_000)
            dbus = i2cdisplaybus.I2CDisplayBus(bus, device_address=0x3c)
            return adafruit_displayio_ssd1306.SSD1306(dbus, width=128, height=64)
        except Exception as exc:
            print(f"Display init attempt {i + 1} failed:", exc)
            if bus is not None:
                try:
                    bus.deinit()
                except Exception:
                    pass
            time.sleep(0.5)
    raise RuntimeError("OLED never came up -- check wiring")


display = init_display()
display.auto_refresh = False

main_group = displayio.Group()
display.root_group = main_group

mono = displayio.Palette(2)
mono[0] = 0x000000
mono[1] = 0xFFFFFF


def new_bitmap(width, height):
    return displayio.Bitmap(width, height, 2)


def draw_bar(bitmap, pct):
    """Hollow rectangle with a solid fill proportional to pct (0-100)."""
    w, h = bitmap.width, bitmap.height
    fill_rect(bitmap, 0, 0, w, h, 0)
    fill_rect(bitmap, 0, 0, w, 1, 1)
    fill_rect(bitmap, 0, h - 1, w, h, 1)
    fill_rect(bitmap, 0, 0, 1, h, 1)
    fill_rect(bitmap, w - 1, 0, w, h, 1)
    if pct < 0:
        pct = 0
    elif pct > 100:
        pct = 100
    filled = ((w - 4) * pct) // 100
    if filled > 0:
        fill_rect(bitmap, 2, 2, 2 + filled, h - 2, 1)


def fit(text, chars=21):
    return text[:chars]


# --- Screen: the face ---
eyes = Eyes()
face_time_label = label.Label(terminalio.FONT, text="", scale=1, x=2, y=6)
face_pct_label = label.Label(terminalio.FONT, text="", scale=1, x=100, y=6)
face_date_label = label.Label(terminalio.FONT, text="", scale=1, x=34, y=58)

# small note glyph, shown in the corner whenever music is playing
note_bitmap = new_bitmap(6, 8)
fill_rect(note_bitmap, 4, 0, 6, 5, 1)        # stem
fill_rect(note_bitmap, 0, 4, 5, 8, 1)        # head
fill_rect(note_bitmap, 1, 5, 4, 7, 0)        # hollow it out
face_note = displayio.TileGrid(note_bitmap, pixel_shader=mono, x=38, y=1)
face_note.hidden = True

face_group = displayio.Group()
face_group.append(eyes.group)
face_group.append(face_time_label)
face_group.append(face_pct_label)
face_group.append(face_date_label)
face_group.append(face_note)
main_group.append(face_group)

# --- Screen: two lines of text (timer) ---
text_group = displayio.Group()
time_label = label.Label(terminalio.FONT, text="Booting...", scale=2, x=16, y=22)
date_label = label.Label(terminalio.FONT, text="Please Wait", scale=1, x=16, y=50)
text_group.append(time_label)
text_group.append(date_label)
main_group.append(text_group)

# --- Screen: weather ---
icon_bitmap = new_bitmap(ICON_SIZE, ICON_SIZE)
weather_group = displayio.Group()
wx_time_label = label.Label(terminalio.FONT, text="--:--", scale=3, x=2, y=22)
wx_temp_label = label.Label(terminalio.FONT, text="--.-C", scale=2, x=2, y=46)
wx_desc_label = label.Label(terminalio.FONT, text="", scale=1, x=2, y=58)
weather_group.append(displayio.TileGrid(icon_bitmap, pixel_shader=mono, x=96, y=8))
weather_group.append(wx_time_label)
weather_group.append(wx_temp_label)
weather_group.append(wx_desc_label)
main_group.append(weather_group)

# --- Screen: Spotify ---
sp_bar = new_bitmap(124, 6)
spotify_group = displayio.Group()
sp_track_label = label.Label(terminalio.FONT, text="", scale=1, x=2, y=13)
sp_artist_label = label.Label(terminalio.FONT, text="", scale=1, x=2, y=25)
sp_state_label = label.Label(terminalio.FONT, text="", scale=1, x=2, y=46)
sp_hint_label = label.Label(terminalio.FONT, text="tap play  hold next",
                            scale=1, x=2, y=57)
spotify_group.append(displayio.TileGrid(sp_bar, pixel_shader=mono, x=2, y=32))
spotify_group.append(sp_track_label)
spotify_group.append(sp_artist_label)
spotify_group.append(sp_state_label)
spotify_group.append(sp_hint_label)
main_group.append(spotify_group)

# --- Screen: upcoming calendar events ---
calendar_group = displayio.Group()
cal_index_label = label.Label(terminalio.FONT, text="", scale=1, x=2, y=11)
cal_when_label = label.Label(terminalio.FONT, text="", scale=1, x=60, y=11)
cal_line1_label = label.Label(terminalio.FONT, text="", scale=1, x=2, y=28)
cal_line2_label = label.Label(terminalio.FONT, text="", scale=1, x=2, y=40)
cal_in_label = label.Label(terminalio.FONT, text="", scale=1, x=2, y=56)
calendar_group.append(cal_index_label)
calendar_group.append(cal_when_label)
calendar_group.append(cal_line1_label)
calendar_group.append(cal_line2_label)
calendar_group.append(cal_in_label)
main_group.append(calendar_group)

# --- Screen: Claude usage ---
usage_bar = new_bitmap(124, 12)
usage_group = displayio.Group()
usage_pct_label = label.Label(terminalio.FONT, text="--%", scale=2, x=4, y=18)
usage_scope_label = label.Label(terminalio.FONT, text="SESSION", scale=1, x=62, y=12)
usage_reset_label = label.Label(terminalio.FONT, text="--", scale=1, x=62, y=24)
usage_week_label = label.Label(terminalio.FONT, text="", scale=1, x=4, y=56)
usage_group.append(displayio.TileGrid(usage_bar, pixel_shader=mono, x=2, y=36))
usage_group.append(usage_pct_label)
usage_group.append(usage_scope_label)
usage_group.append(usage_reset_label)
usage_group.append(usage_week_label)
main_group.append(usage_group)

# --- Screen: PC system stats ---
cpu_bar = new_bitmap(124, 8)
ram_bar = new_bitmap(124, 8)
system_group = displayio.Group()
cpu_label = label.Label(terminalio.FONT, text="CPU --%", scale=1, x=2, y=10)
temp_label = label.Label(terminalio.FONT, text="", scale=1, x=90, y=10)
ram_label = label.Label(terminalio.FONT, text="RAM --%", scale=1, x=2, y=32)
ram_detail_label = label.Label(terminalio.FONT, text="", scale=1, x=62, y=32)
sys_foot_label = label.Label(terminalio.FONT, text="", scale=1, x=2, y=57)
system_group.append(displayio.TileGrid(cpu_bar, pixel_shader=mono, x=2, y=16))
system_group.append(displayio.TileGrid(ram_bar, pixel_shader=mono, x=2, y=38))
system_group.append(cpu_label)
system_group.append(temp_label)
system_group.append(ram_label)
system_group.append(ram_detail_label)
system_group.append(sys_foot_label)
main_group.append(system_group)

# --- Screen: the games menu, and the games themselves ---
# Both games are built the first time you open them. Each carries its own
# 128x64 bitmap and a pile of labels, and most sessions never touch them.
game = None
ball = None
DINO_PLAYING = 1              # filled in properly when dino.py loads


def ensure_dino():
    global game, DINO_PLAYING
    if game is None:
        from dino import DinoGame, PLAYING
        DINO_PLAYING = PLAYING
        game = DinoGame()
        main_group.append(game.group)
    return game


def ensure_ball():
    global ball
    if ball is None:
        from eightball import EightBall
        ball = EightBall()
        main_group.append(ball.group)
    return ball


games_group = displayio.Group()
games_title = label.Label(terminalio.FONT, text="GAMES", scale=2, x=34, y=14)
games_items = [
    label.Label(terminalio.FONT, text="", scale=1, x=8, y=32),
    label.Label(terminalio.FONT, text="", scale=1, x=8, y=44),
]
games_hint = label.Label(terminalio.FONT, text="tap pick  hold start",
                         scale=1, x=4, y=58)
games_group.append(games_title)
for lbl in games_items:
    games_group.append(lbl)
games_group.append(games_hint)
main_group.append(games_group)

game_index = 0
games_state = "menu"          # "menu" | "dino" | "eightball"


def render_games_menu():
    for i, lbl in enumerate(games_items):
        if i < len(GAMES):
            lbl.text = ("> " if i == game_index else "  ") + GAMES[i]
        else:
            lbl.text = ""

# --- Overlay: tab indicator dots ---
DOT_SLOT = 8
dots_bitmap = new_bitmap(len(MODES) * DOT_SLOT, 4)
dots_tile = displayio.TileGrid(dots_bitmap, pixel_shader=mono,
                               x=(128 - len(MODES) * DOT_SLOT) // 2, y=0)
main_group.append(dots_tile)


def draw_dots(active):
    fill_rect(dots_bitmap, 0, 0, dots_bitmap.width, 4, 0)
    for i in range(len(MODES)):
        cx = i * DOT_SLOT + DOT_SLOT // 2
        if i == active:
            fill_rect(dots_bitmap, cx - 3, 0, cx + 3, 3, 1)
        else:
            fill_rect(dots_bitmap, cx - 1, 1, cx + 1, 3, 1)


# --- Overlay: meeting popup, sits above everything including the dots ---
POPUP_W, POPUP_H = 120, 44
popup_bitmap = new_bitmap(POPUP_W, POPUP_H)
fill_rect(popup_bitmap, 0, 0, POPUP_W, POPUP_H, 1)          # white border
fill_rect(popup_bitmap, 2, 2, POPUP_W - 2, POPUP_H - 2, 0)  # black inside
popup_group = displayio.Group()
popup_title = label.Label(terminalio.FONT, text="", scale=1, x=0, y=26)
popup_when = label.Label(terminalio.FONT, text="", scale=2, x=0, y=41)
popup_hint = label.Label(terminalio.FONT, text="", scale=1, x=0, y=54)
popup_group.append(displayio.TileGrid(popup_bitmap, pixel_shader=mono, x=4, y=10))
popup_group.append(popup_title)
popup_group.append(popup_when)
popup_group.append(popup_hint)
main_group.append(popup_group)
popup_group.hidden = True


def centre(lbl, text, char_w=6):
    lbl.text = text
    lbl.x = max(0, (128 - len(text) * char_w) // 2)


def set_lines(big, small):
    time_label.text = big
    time_label.x = max(0, (128 - len(big) * 12) // 2)
    date_label.text = small
    date_label.x = max(0, (128 - len(small) * 6) // 2)


def show_screen(which):
    face_group.hidden = which != "face"
    text_group.hidden = which != "text"
    weather_group.hidden = which != "weather"
    calendar_group.hidden = which != "calendar"
    spotify_group.hidden = which != "spotify"
    usage_group.hidden = which != "usage"
    system_group.hidden = which != "system"
    games_group.hidden = which != "games"
    if game is not None:
        game.group.hidden = which != "dino"
    if ball is not None:
        ball.group.hidden = which != "eightball"
    # a game wants the whole panel; the menu is happy to share
    dots_tile.hidden = which in ("dino", "eightball")


show_screen("text")
draw_dots(0)
boot_mark("screens built")


# --- 3. NETWORK ---
ssid = os.getenv("WIFI_SSID")
password = os.getenv("WIFI_PASSWORD")
api_key = os.getenv("OPENWEATHER_TOKEN")

pool = None
ssl_context = None
requests = None


def online():
    try:
        return bool(wifi.radio.connected)
    except AttributeError:
        # older builds lack .connected; an address means we're associated
        return wifi.radio.ipv4_address is not None
    except Exception:
        return False


def wait_for_ip(timeout=6.0):
    """Association and having an address are two different moments.

    On a cold boot connect() can return before DHCP has finished, and any
    socket opened in that window fails. A soft reload never hits this,
    because the address survives from the previous run.
    """
    started = time.monotonic()
    while time.monotonic() - started < timeout:
        try:
            if wifi.radio.ipv4_address is not None:
                return True
        except Exception:
            pass
        time.sleep(0.2)
    return False


def connect_wifi(attempts=5, show=True):
    """Try to associate, a few times.

    A cold power-up is slower than a soft reload: the radio firmware has to
    load and associate from scratch, and the first attempt often fails.
    During development you almost never see this, because saving a file
    triggers a soft reload that keeps WiFi up from the previous run.
    """
    for i in range(attempts):
        if show:
            set_lines("Wi-Fi", f"Connecting {i + 1}/{attempts}")
            display.refresh()
        try:
            wifi.radio.connect(ssid, password)
            if online() and wait_for_ip():
                print("Wi-Fi up, address", wifi.radio.ipv4_address)
                return True
        except Exception as exc:
            print(f"Wi-Fi attempt {i + 1} failed:", exc)
        if i + 1 < attempts:
            time.sleep(1.5)
    return False


def rebuild_session():
    """Fresh socket pool and session after WiFi comes back.

    Sockets opened before a drop are dead, but the pool doesn't know that.
    Without this, the first requests after reconnecting fail like the
    bridge is still unreachable.
    """
    global pool, ssl_context, requests
    try:
        adafruit_connection_manager.connection_manager_close_all(release_references=True)
    except Exception:
        pass
    pool = adafruit_connection_manager.get_radio_socketpool(wifi.radio)
    ssl_context = adafruit_connection_manager.get_radio_ssl_context(wifi.radio)
    requests = adafruit_requests.Session(pool, ssl_context)


print("Connecting Wi-Fi...")
if connect_wifi(attempts=8 if COLD_BOOT else 5):
    boot_mark("wifi connected")
else:
    boot_mark("wifi FAILED -- continuing offline")
rebuild_session()
time.sleep(0.3)          # let the radio finish settling before the first socket


# --- Burn-in protection ---
SHIFT_OFFSETS = ((0, 0), (1, 0), (2, 1), (1, 2), (0, 1))
shift_index = 0
next_shift = 0.0
SHIFT_INTERVAL = 180.0

current_brightness = None


def set_brightness(value):
    global current_brightness
    if value == current_brightness:
        return
    try:
        display.brightness = value
        current_brightness = value
    except Exception:
        current_brightness = value


# --- 4. DATA FETCHING ---
time_synced = False
last_time_sync = -999.0
TIME_RESYNC = 6 * 3600.0


def apply_clock(parts, now):
    """Set the RTC from a [Y, M, D, h, m, s] list."""
    global time_synced, last_time_sync
    try:
        rtc.RTC().datetime = time.struct_time(
            (parts[0], parts[1], parts[2],
             parts[3], parts[4], parts[5], 0, 0, -1))
        time_synced = True
        last_time_sync = now
        return True
    except Exception as exc:
        print("Clock set failed:", exc)
        return False


def get_time_https():
    """Fallback only. A TLS handshake here costs several seconds at boot."""
    print("Syncing time over HTTPS...")
    r = None
    try:
        url = "https://timeapi.io/api/Time/current/zone?timeZone=Europe/Athens"
        r = requests.get(url)
        d = r.json()
        return apply_clock([d["year"], d["month"], d["day"],
                            d["hour"], d["minute"], d["seconds"]],
                           time.monotonic())
    except Exception as e:
        print("Time Error:", e)
        return False
    finally:
        if r is not None:
            try:
                r.close()
            except Exception:
                pass


weather_temp = "--.-C"
weather_desc = "no data yet"
weather_icon = ""
weather_mood = "neutral"
last_weather_fetch = -999.0
WEATHER_REFRESH = 600.0


def fetch_weather(now):
    global weather_temp, weather_desc, weather_icon, weather_mood
    global last_weather_fetch
    last_weather_fetch = now
    r = None
    try:
        url = (f"http://api.openweathermap.org/data/2.5/weather"
               f"?q={CITY}&appid={api_key}&units={UNITS}")
        r = requests.get(url)
        d = r.json()
    except Exception:
        weather_temp, weather_desc, weather_icon = "Net Err", "retry later", ""
        return
    finally:
        if r is not None:
            try:
                r.close()
            except Exception:
                pass

    if "main" not in d:
        weather_temp, weather_desc, weather_icon = "Key Err", "check token", ""
        return

    weather_temp = f"{d['main']['temp']:.1f}C"
    entry = d["weather"][0]
    weather_desc = entry.get("description", "")[:21]
    weather_icon = entry.get("icon", "")

    # Recorded rather than applied: context_mood() decides what actually wins.
    low = weather_desc.lower()
    if "rain" in low or "storm" in low or "snow" in low:
        weather_mood = "sad"
    elif "clear" in low:
        weather_mood = "happy"
    else:
        weather_mood = "neutral"


def render_weather():
    t = time.localtime()
    wx_time_label.text = f"{t.tm_hour:02d}:{t.tm_min:02d}"
    wx_temp_label.text = weather_temp
    wx_desc_label.text = weather_desc
    draw_weather(icon_bitmap, weather_icon)


# --- Everything from the PC bridge, in one request ---
status_ok = False
usage_ok = False
usage_session_pct = 0
usage_session_reset = "--"
usage_week_pct = 0
usage_week_reset = "--"
usage_alerted = False
sys_cpu = 0
sys_ram = 0
sys_ram_used = 0.0
sys_ram_total = 0.0
sys_temp = None
sys_disk = 0
sys_uptime = "?"
sys_uptime_min = 0
sp_ok = False
sp_active = False
sp_playing = False
sp_track = ""
sp_artist = ""
sp_progress = 0
cal_ok = False
event_title = ""
event_in = None
event_at = ""
events = []
cal_index = 0
last_status_fetch = -999.0
bridge_failures = 0


last_net_error = ""          # shown on the system tab when the bridge is down


class NetworkStuck(Exception):
    """Raised when the network stack is provably dead; code.py soft-resets."""


# A soft reset is the only thing that clears the dead-stack state, and it only
# works once the network is actually ready -- which on a cold boot can take a
# minute or two. So we allow several, counted in non-volatile memory because
# ordinary variables don't survive a reset. code.py zeroes it on power-on.
STUCK_RESTART_LIMIT = 10


def _stuck_count():
    try:
        value = microcontroller.nvm[0]
        return value if value <= STUCK_RESTART_LIMIT else 0   # fresh flash reads 255
    except Exception:
        return 0


def _set_stuck_count(value):
    try:
        if microcontroller.nvm[0] != value:     # avoid needless flash writes
            microcontroller.nvm[0] = value
    except Exception:
        pass


def dns_works():
    """Can we resolve a public name? If not, nothing is getting through."""
    try:
        pool.getaddrinfo("api.openweathermap.org", 80)
        return True
    except Exception:
        return False


def network_stuck_restart():
    """Bridge dead AND DNS dead while WiFi claims to be up.

    That's not the bridge being off -- that's the Pico's network stack wedged,
    which happens when it talks too early after a cold boot. A soft reset
    clears it. Bounded, so a genuinely broken network can't reset forever.
    """
    count = _stuck_count()
    if count >= STUCK_RESTART_LIMIT:
        print(f"Network still dead after {count} restarts -- no more restarts")
        return
    _set_stuck_count(count + 1)
    print(f"Network stack stuck -- soft reset {count + 1}/{STUCK_RESTART_LIMIT}")
    set_lines("Network", f"reset {count + 1}/{STUCK_RESTART_LIMIT}")
    display.refresh()
    time.sleep(2.0)                     # give the network a little longer
    raise NetworkStuck()
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

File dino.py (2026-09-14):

# dino.py -- one-button endless runner for a 128x64 SSD1306
#
#     from dino import DinoGame
#     game = DinoGame()
#     main_group.append(game.group)
#     game.press()                 # start / jump / retry
#     game.tick(now, sfx)          # every loop
#
# Drawn into a single 1-bit Bitmap like the eyes, so no per-frame allocation.
# Physics are time-based rather than per-frame, so the feel doesn't change
# when the loop speeds up or slows down.

import time
import random
import displayio
import terminalio
from adafruit_display_text import label

from eyes import _fill as fill_rect

W, H = 128, 64
GROUND_Y = 52               # top of the ground line
DINO_X = 12
DINO_W, DINO_H = 10, 14

# Tuning. A 128px screen gives you very little reaction time, so this is
# deliberately gentler than the Chrome original: a floatier jump, slower
# start, a gentle ramp, and generous gaps between obstacles.
GRAVITY = 640.0             # px/s^2
JUMP_V = -200.0             # px/s, roughly a 31px apex over 0.63s
START_SPEED = 46.0          # px/s
MAX_SPEED = 104.0
RAMP = 0.032                # speed gained per point of score
JUMP_BUFFER = 0.22          # press slightly early and it still counts

TITLE, PLAYING, OVER = 0, 1, 2


class DinoGame:
    def __init__(self):
        self.bitmap = displayio.Bitmap(W, H, 2)
        palette = displayio.Palette(2)
        palette[0] = 0x000000
        palette[1] = 0xFFFFFF

        self.group = displayio.Group()
        self.group.append(displayio.TileGrid(self.bitmap, pixel_shader=palette))

        self.score_label = label.Label(terminalio.FONT, text="", scale=1, x=96, y=9)
        self.hi_label = label.Label(terminalio.FONT, text="", scale=1, x=2, y=9)
        self.line1 = label.Label(terminalio.FONT, text="", scale=1, x=0, y=22)
        self.line2 = label.Label(terminalio.FONT, text="", scale=1, x=0, y=34)
        for lbl in (self.score_label, self.hi_label, self.line1, self.line2):
            self.group.append(lbl)

        self.high = 0
        self.state = TITLE
        self._last = time.monotonic()
        self.reset(to_title=True)

    # ---------- helpers ----------

    @staticmethod
    def _centre(lbl, text):
        lbl.text = text
        lbl.x = max(0, (W - len(text) * 6) // 2)

    def reset(self, to_title=False):
        self.y = float(GROUND_Y - DINO_H)
        self.vy = 0.0
        self.on_ground = True
        self.obstacles = []
        self.score = 0.0
        self.speed = START_SPEED
        self.ground_offset = 0.0
        self.clouds = [[90.0, 12], [30.0, 20]]
        self.next_spawn = time.monotonic() + 2.2      # a runway before cactus 1
        self.buffered_jump = -10.0
        self._last_point_sound = 0
        self.state = TITLE if to_title else PLAYING
        self._sync_labels()

    def _sync_labels(self):
        title = self.state == TITLE
        over = self.state == OVER
        self.line1.hidden = not (title or over)
        self.line2.hidden = not (title or over)
        self.score_label.hidden = title
        self.hi_label.hidden = title

        if title:
            self._centre(self.line1, "Dinosaurrr rawr")
            self._centre(self.line2, "Press button to start")
        elif over:
            self._centre(self.line1, "GAME OVER")
            self._centre(self.line2, "Press to retry")

    # ---------- input ----------

    def press(self, sfx=None):
        """Button 2: start, jump, or retry depending on state."""
        if self.state == TITLE:
            self.reset()
            self.state = PLAYING
            self._sync_labels()
            if sfx:
                sfx.play("start")
        elif self.state == PLAYING:
            if self.on_ground:
                self._jump(sfx)
            else:
                # pressed a fraction too early -- remember it and fire on landing
                self.buffered_jump = time.monotonic()
        else:                                   # OVER
            self.reset()
            self.state = PLAYING
            self._sync_labels()
            if sfx:
                sfx.play("start")

    def _jump(self, sfx):
        self.vy = JUMP_V
        self.on_ground = False
        self.buffered_jump = -10.0
        if sfx:
            sfx.play("jump")

    # ---------- update ----------

    def tick(self, now=None, sfx=None):
        now = now or time.monotonic()
        dt = now - self._last
        self._last = now
        if dt > 0.05:                # a network stall shouldn't teleport things
            dt = 0.05

        if self.state == PLAYING:
            self._update(dt, now, sfx)

        self._draw()

    def _update(self, dt, now, sfx):
        # dino physics
        if not self.on_ground:
            self.vy += GRAVITY * dt
            self.y += self.vy * dt
            floor = float(GROUND_Y - DINO_H)
            if self.y >= floor:
                self.y = floor
                self.vy = 0.0
                self.on_ground = True
                if now - self.buffered_jump < JUMP_BUFFER:
                    self._jump(sfx)

        # world scroll, accelerating with score
        self.speed = min(MAX_SPEED, START_SPEED + self.score * RAMP)
        shift = self.speed * dt
        self.ground_offset = (self.ground_offset + shift) % 8

        for cloud in self.clouds:
            cloud[0] -= shift * 0.25
            if cloud[0] < -20:
                cloud[0] = W + random.uniform(5, 45)
                cloud[1] = random.randint(8, 24)

        for obstacle in self.obstacles:
            obstacle[0] -= shift
        self.obstacles = [o for o in self.obstacles if o[0] + o[1] > -2]

        # spawning -- gaps shrink as things speed up, but stay clearable
        if now >= self.next_spawn:
            tall = random.random() < 0.22
            width = 7 if tall else 5
            height = 14 if tall else 9
            self.obstacles.append([float(W + 4), width, height])
            gap = random.uniform(1.25, 2.3) * (START_SPEED / self.speed)
            self.next_spawn = now + max(0.85, gap)

        # score
        before = int(self.score)
        self.score += dt * 10.0
        after = int(self.score)
        if sfx and after // 100 > self._last_point_sound:
            self._last_point_sound = after // 100
            sfx.play("point")
        if after != before:
            self.score_label.text = f"{after:04d}"
            self.hi_label.text = f"HI {self.high:04d}"

        # collision, with two pixels of forgiveness on each side
        dino_left = DINO_X + 2
        dino_right = DINO_X + DINO_W - 2
        dino_bottom = self.y + DINO_H
        for x, width, height in self.obstacles:
            if x + width - 2 < dino_left or x + 2 > dino_right:
                continue
            if dino_bottom > GROUND_Y - height + 2:
                self._game_over(sfx)
                break
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

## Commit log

2026-09-14 Mimic: code, case, bridge and site
    [case.scad, lid.stl, spacer.stl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]
2026-09-14 Correct wiring to real pins and breadboard holes; eight screens
2026-09-17 Real screens and photos, corrected wiring, bridge dependencies, games menu controls
    [code.py, make_photos.py, make_sheet.py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]
2026-09-23 Fix autorun on power-up
    [code.py]
2026-09-25 Split code.py into launcher and app.py; rewrite README for current features
